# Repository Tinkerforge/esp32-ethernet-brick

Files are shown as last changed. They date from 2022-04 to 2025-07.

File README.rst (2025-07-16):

ESP32 Ethernet Brick
====================

This repository contains the firmware source code and the hardware design
files. The documentation generator configs can be found at
https://github.com/Tinkerforge/generators

Repository Overview
-------------------

.. DO NOT EDIT THIS OVERVIEW MANUALLY! CHANGE https://github.com/Tinkerforge/esp32-firmware/repo_overview.rst AND COPY THAT BLOCK INTO ALL REPOS LISTED BELOW. TODO: AUTOMATE THIS

Software
~~~~~~~~
- `esp32-firmware <https://github.com/Tinkerforge/esp32-firmware>`__  **Please report any issues concerning WARP hard- and software here!** Source code of the ESP32 firmware shared between all WARP Chargers and Energy Managers

- `tfjson <https://github.com/Tinkerforge/tfjson>`__ SAX style JSON serializer and deserializer
- `tfmodbustcp <https://github.com/Tinkerforge/tfmodbustcp>`__ Modbus TCP server and client implementation
- `tfocpp <https://github.com/Tinkerforge/tfocpp>`__ OCPP 1.6 implementation
- `tftools <https://github.com/Tinkerforge/tftools>`__ Miscellaneous tools and helpers

- `esp32-remote-access <https://github.com/Tinkerforge/esp32-remote-access>`__ Source code of the my.warp-charger.com remote access server

- `warp-charger <https://github.com/Tinkerforge/warp-charger>`__ The source code of (docs.)warp-charger.com and the printed manual, released firmwares, datasheets and documents, as well as some tools and hardware design files
- `api.warp-charger.com <https://github.com/Tinkerforge/api.warp-charger.com>`__ Serves APIs that are used by WARP Chargers to obtain relevant public information like day ahead prices
- `vislog.warp-charger.com <https://github.com/Tinkerforge/vislog.warp-charger.com>`__ Visualizes WARP Charger logs and EVSE debug protocols
- `dbus-warp-charger <https://github.com/Tinkerforge/dbus-warp-charger>`__ Integrates WARP Chargers into a Victron Energy Venus OS device (e.g. Cerbo GX)

WARP Charger Hardware
~~~~~~~~~~~~~~~~~~~~~~

- `esp32-brick <https://github.com/Tinkerforge/esp32-brick>`__ Hardware design files of the ESP32 Brick
- `evse-bricklet <https://github.com/Tinkerforge/evse-bricklet>`__  Firmware source code and hardware design files of the EVSE Bricklet
- `rs485-bricklet <https://github.com/Tinkerforge/rs485-bricklet>`__ Firmware source code and hardware design files of the RS485 Bricklet

WARP2 Charger Hardware
~~~~~~~~~~~~~~~~~~~~~~

- `esp32-ethernet-brick <https://github.com/Tinkerforge/esp32-ethernet-brick>`__ Hardware design files of the ESP32 Ethernet Brick
- `evse-v2-bricklet <https://github.com/Tinkerforge/evse-v2-bricklet>`__ Firmware source code and hardware design files of the EVSE 2.0 Bricklet
- `nfc-bricklet <https://github.com/Tinkerforge/nfc-bricklet>`__ Firmware source code and hardware design files of the NFC Bricklet

WARP3 Charger Hardware
~~~~~~~~~~~~~~~~~~~~~~

- `warp-esp32-ethernet-brick <https://github.com/Tinkerforge/warp-esp32-ethernet-brick>`__ Hardware design files of the WARP ESP32 Ethernet Brick
- `evse-v3-bricklet <https://github.com/Tinkerforge/evse-v3-bricklet>`__ Firmware source code and hardware design files of the EVSE 3.0 Bricklet
- `nfc-bricklet <https://github.com/Tinkerforge/nfc-bricklet>`__ Firmware source code and hardware design files of the NFC Bricklet

WARP Energy Manager Hardware
~~~~~~~~~~~~~~~~~~~~~~~~~~~~

- `esp32-ethernet-brick <https://github.com/Tinkerforge/esp32-ethernet-brick>`__ Hardware design files of the ESP32 Ethernet Brick
- `warp-energy-manager-bricklet <https://github.com/Tinkerforge/warp-energy-manager-bricklet>`__ Firmware source code and hardware design files of the WARP Energy Manager Bricklet

WARP Energy Manager 2.0 Hardware
~~~~~~~~~~~~~~~~~~~~~~~~~~~~~~~~

- `esp32-ethernet-brick <https://github.com/Tinkerforge/esp32-ethernet-brick>`__ Hardware design files of the ESP32 Ethernet Brick
- `warp-energy-manager-v2-bricklet <https://github.com/Tinkerforge/warp-energy-manager-v2-bricklet>`__ Firmware source code and hardware design files of the WARP Energy Manager 2.0 Bricklet
- `warp-front-panel-bricklet <https://github.com/Tinkerforge/warp-front-panel-bricklet>`__ Firmware source code and hardware design files of the WARP Front Panel Bricklet

Forked/patched projects
~~~~~~~~~~~~~~~~~~~~~~~

- `arduino-esp32 <https://github.com/Tinkerforge/arduino-esp32>`__
- `esp32-arduino-libs <https://github.com/Tinkerforge/esp32-arduino-libs>`__
- `WireGuard-ESP32-Arduino <https://github.com/Tinkerforge/WireGuard-ESP32-Arduino>`__

Repository Content
------------------

hardware/:
 * Contains KiCad project files and additionally schematics as PDF

datasheets/:
 * Contains datasheets for sensors and complex ICs that are used

Hardware
--------

The hardware is designed with the open source EDA Suite KiCad
(http://www.kicad.org). Before you are able to open the files,
you have to install the Tinkerforge kicad-libraries
(https://github.com/Tinkerforge/kicad-libraries). You can either clone
them directly in hardware/ or clone them in a separate folder and
symlink them into hardware/
(ln -s kicad_path/kicad-libraries project_path/hardware). After that you
can open the .pro file in hardware/ with KiCad and from there view and
modify the schematics and the PCB layout.

Software
--------

The software for all Bricks based on the ESP32 can be found at:
https://github.com/Tinkerforge/esp32-firmware/tree/master/software

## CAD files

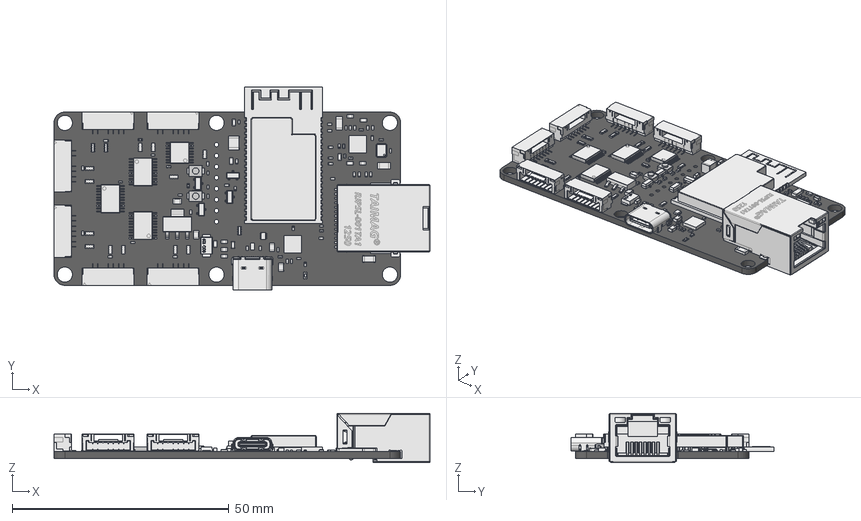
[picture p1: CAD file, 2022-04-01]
hardware/esp32-ethernet.FCStd
86.8 x 46.7 x 11.4 mm
Pcb_1a05
ESP32-WROVER-E
ESP32-WROVER-E001
ESP32-WROVER-E002
ESP32-WROVER-E003
ESP32-WROVER-E004
ESP32-WROVER-E005
ESP32-WROVER-E006
ESP32-WROVER-E007
ESP32-WROVER-E008
ESP32-WROVER-E009
ESP32-WROVER-E010
ESP32-WROVER-E011
ESP32-WROVER-E012
ESP32-WROVER-E013
ESP32-WROVER-E014
ESP32-WROVER-E015
ESP32-WROVER-E016
ESP32-WROVER-E017
ESP32-WROVER-E018
ESP32-WROVER-E019
ESP32-WROVER-E020
ESP32-WROVER-E021
ESP32-WROVER-E022
ESP32-WROVER-E023
ESP32-WROVER-E024
ESP32-WROVER-E025
ESP32-WROVER-E026
ESP32-WROVER-E027
ESP32-WROVER-E028
ESP32-WROVER-E029
ESP32-WROVER-E030
ESP32-WROVER-E031
ESP32-WROVER-E032
ESP32-WROVER-E033
ESP32-WROVER-E034
ESP32-WROVER-E035
ESP32-WROVER-E036
ESP32-WROVER-E037
ESP32-WROVER-E038
ESP32-WROVER-E039
ESP32-WROVER-E040
R107_R_0402_5E99F300 x 37
SW101_B3U_1000P[]_5F5B68B4 x 2
Q102_SOT23_5E999EC0 x 4
RP104_Cut_5E9D7D33 x 15
U203_TSSOP-20_5E99A0A3 x 3
P206_BrickletConn_7pin_5E9D989A x 6
L104_R_0603_5E999E38 x 5
USB4105
USB4106
C111_C_0805_5E999D16 x 4
U103_QFN-24_4x4mm_Pitch0.5mm_5E99F04F x 2
C107_C_0402_5E99FA0A x 19
C112_C_0603_604B6DD5 x 7
C303_C_1206_604F2960 x 3
U204_TSSOP-16_604B6FE5
C105_C_1210_604BAACF
Ethernet_Buchse
Ethernet_Buchse001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

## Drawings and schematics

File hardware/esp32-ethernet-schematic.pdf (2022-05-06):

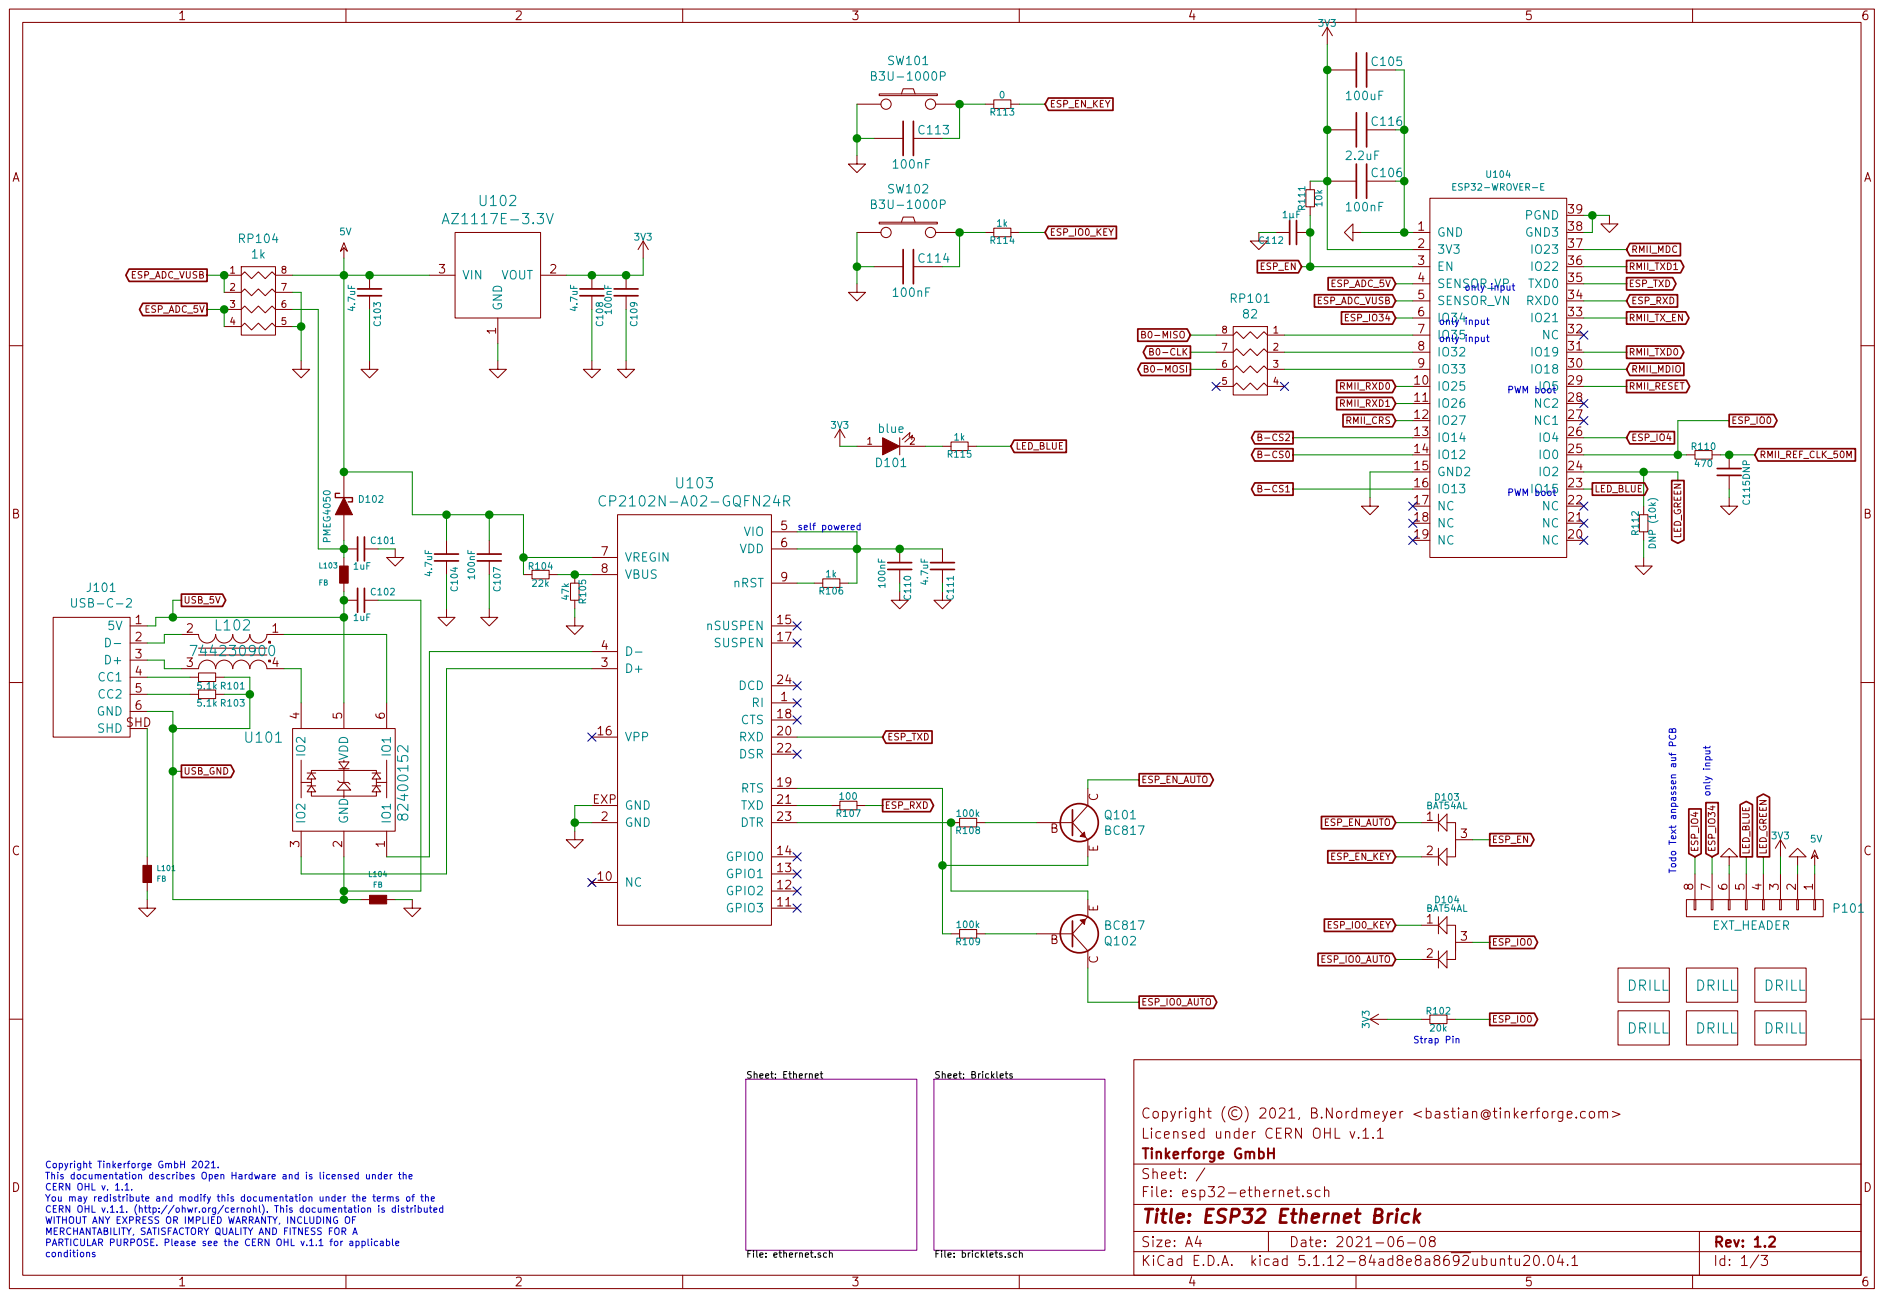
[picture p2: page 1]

Sheet: Bricklets File: bricklets.sch Sheet: Ethernet File: ethernet.sch

Licensed under CERN OHL v.1.1 Copyright (©) 2021, B.Nordmeyer <bastian@tinkerforge.com>

File: esp32-ethernet.sch Sheet: / Tinkerforge GmbH

Copyright Tinkerforge GmbH 2021. This documentation describes Open Hardware and is licensed under the CERN OHL v. 1.1. You may redistribute and modify this documentation under the terms of the CERN OHL v.1.1. (http://ohwr.org/cernohl). This documentation is distributed WITHOUT ANY EXPRESS OR IMPLIED WARRANTY, INCLUDING OF MERCHANTABILITY, SATISFACTORY QUALITY AND FITNESS FOR A

Id: 1/3 Title: ESP32 Ethernet Brick

PARTICULAR PURPOSE. Please see the CERN OHL v.1.1 for applicable

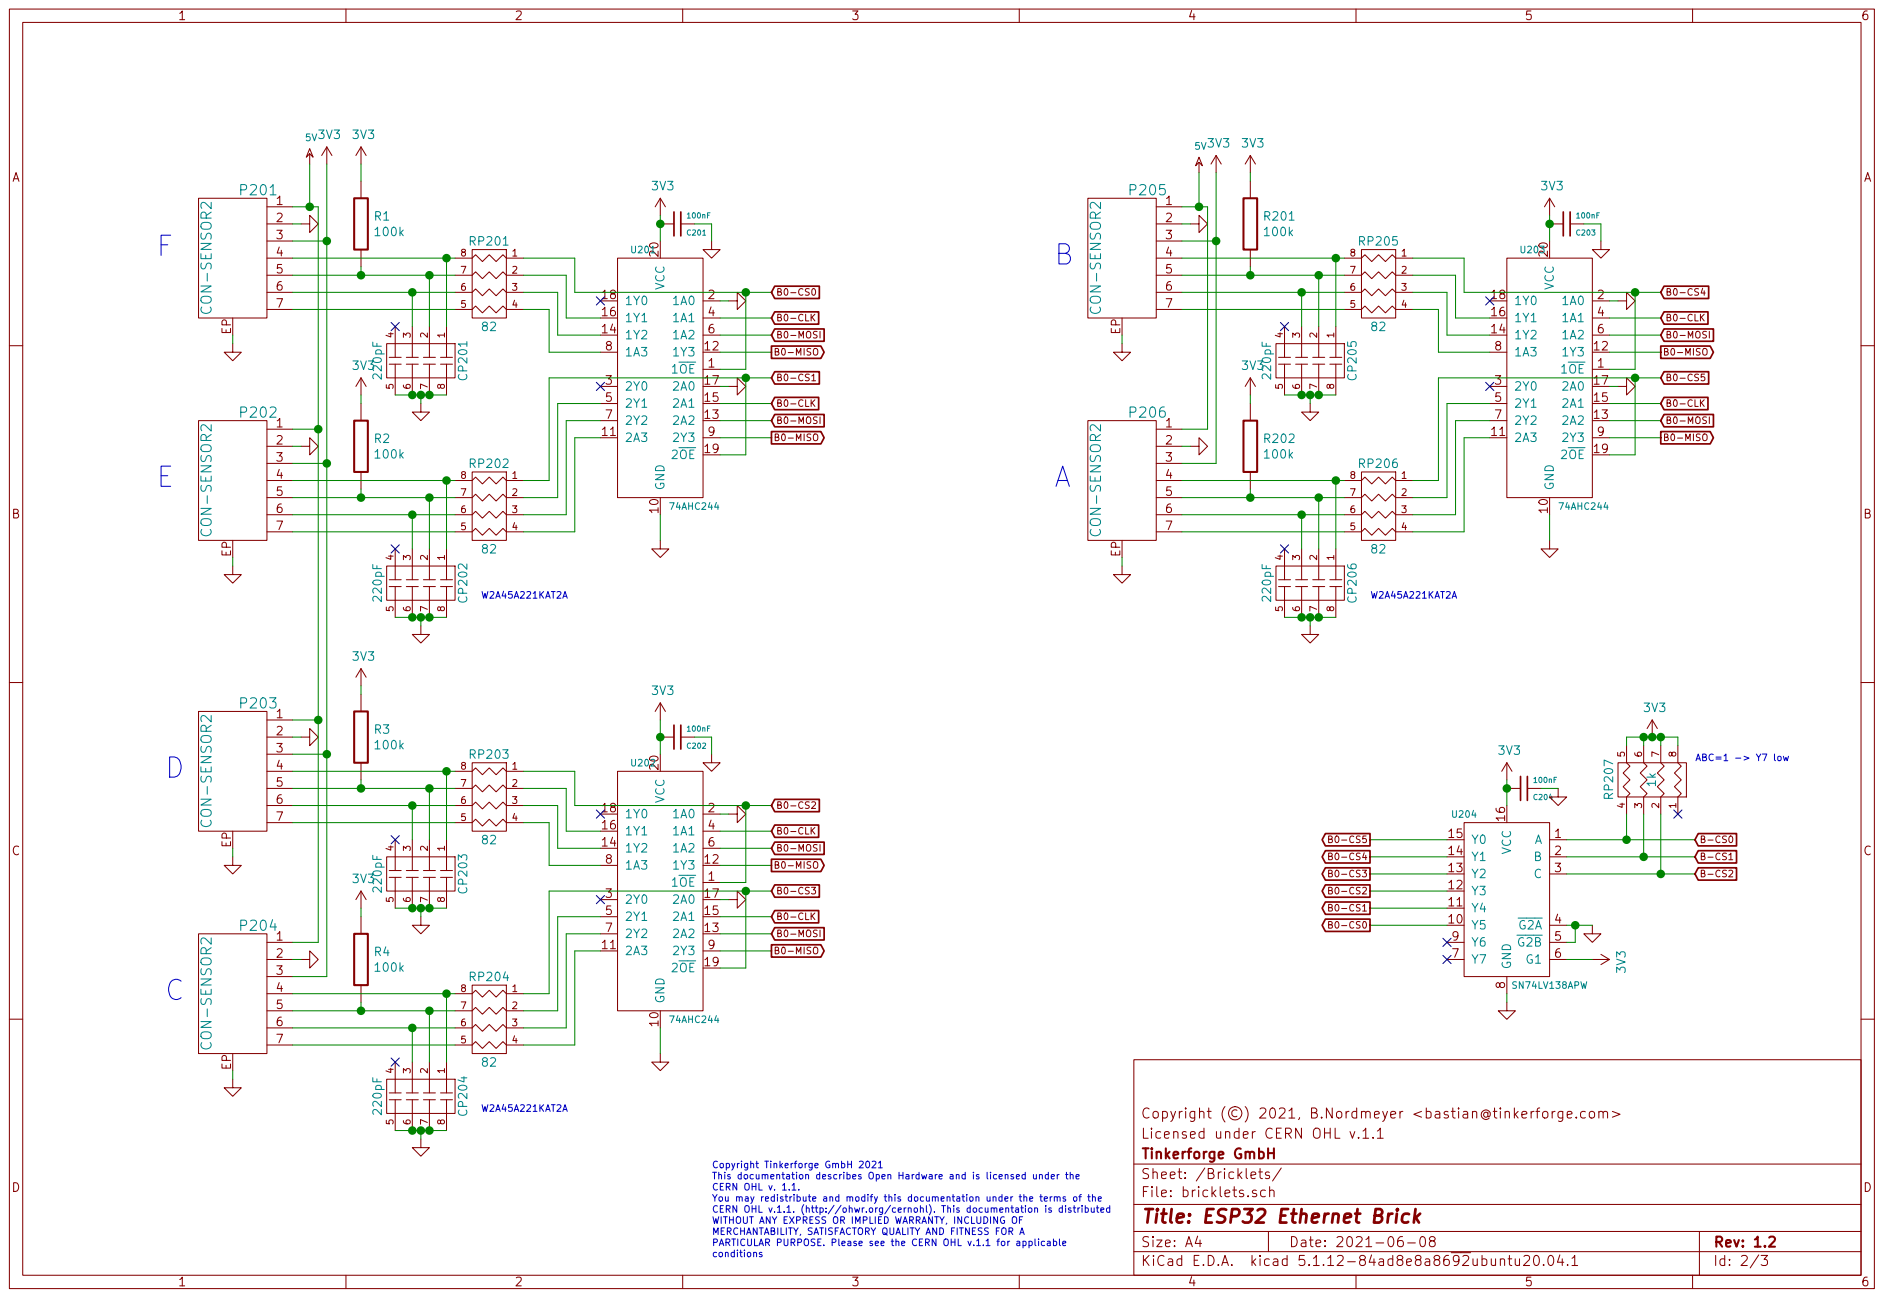
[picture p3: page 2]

Licensed under CERN OHL v.1.1 Copyright (©) 2021, B.Nordmeyer <bastian@tinkerforge.com>

File: bricklets.sch Sheet: /Bricklets/ Tinkerforge GmbH

Id: 2/3 Title: ESP32 Ethernet Brick

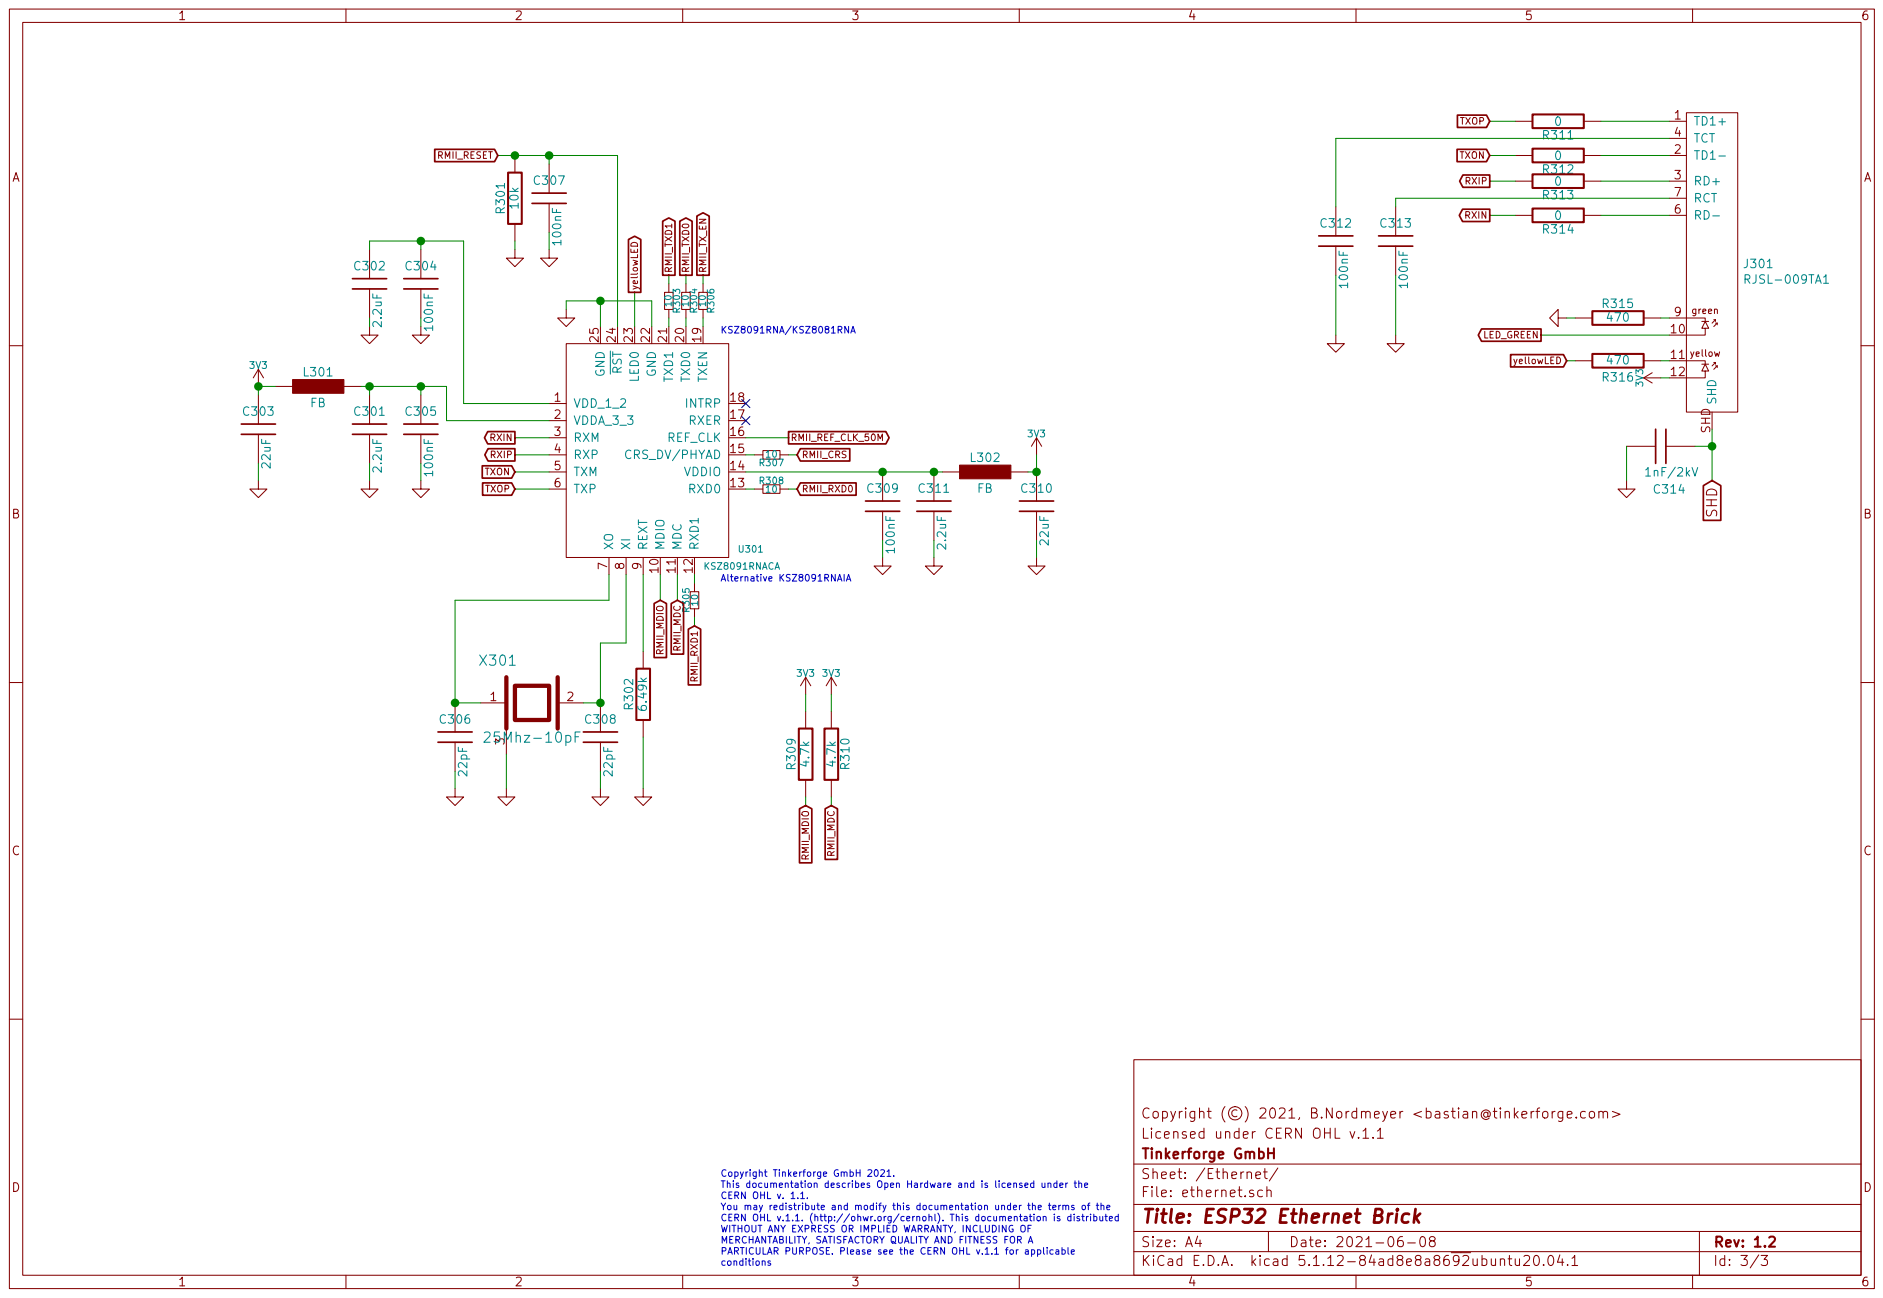
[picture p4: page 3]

Alternative KSZ8091RNAIA Copyright Tinkerforge GmbH 2021. This documentation describes Open Hardware and is licensed under the CERN OHL v. 1.1. You may redistribute and modify this documentation under the terms of the CERN OHL v.1.1. (http://ohwr.org/cernohl). This documentation is distributed WITHOUT ANY EXPRESS OR IMPLIED WARRANTY, INCLUDING OF MERCHANTABILITY, SATISFACTORY QUALITY AND FITNESS FOR A

Licensed under CERN OHL v.1.1 Copyright (©) 2021, B.Nordmeyer <bastian@tinkerforge.com>

File: ethernet.sch Sheet: /Ethernet/ Tinkerforge GmbH

Id: 3/3 Title: ESP32 Ethernet Brick

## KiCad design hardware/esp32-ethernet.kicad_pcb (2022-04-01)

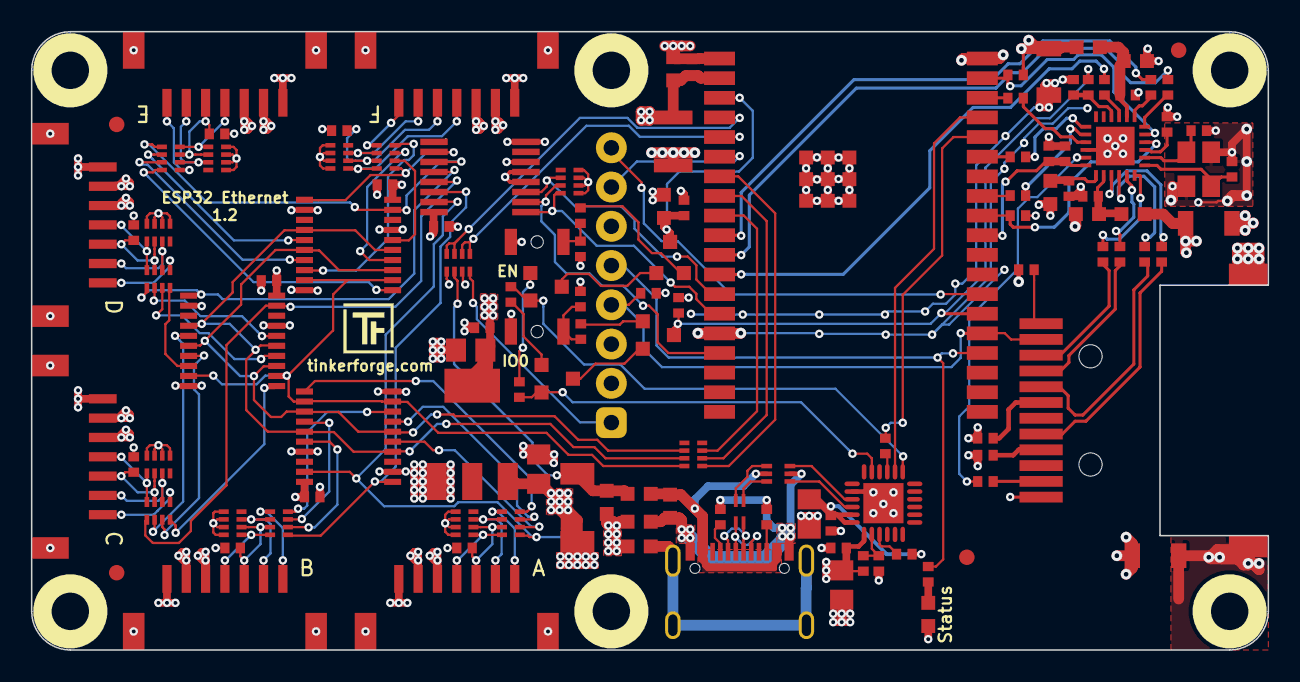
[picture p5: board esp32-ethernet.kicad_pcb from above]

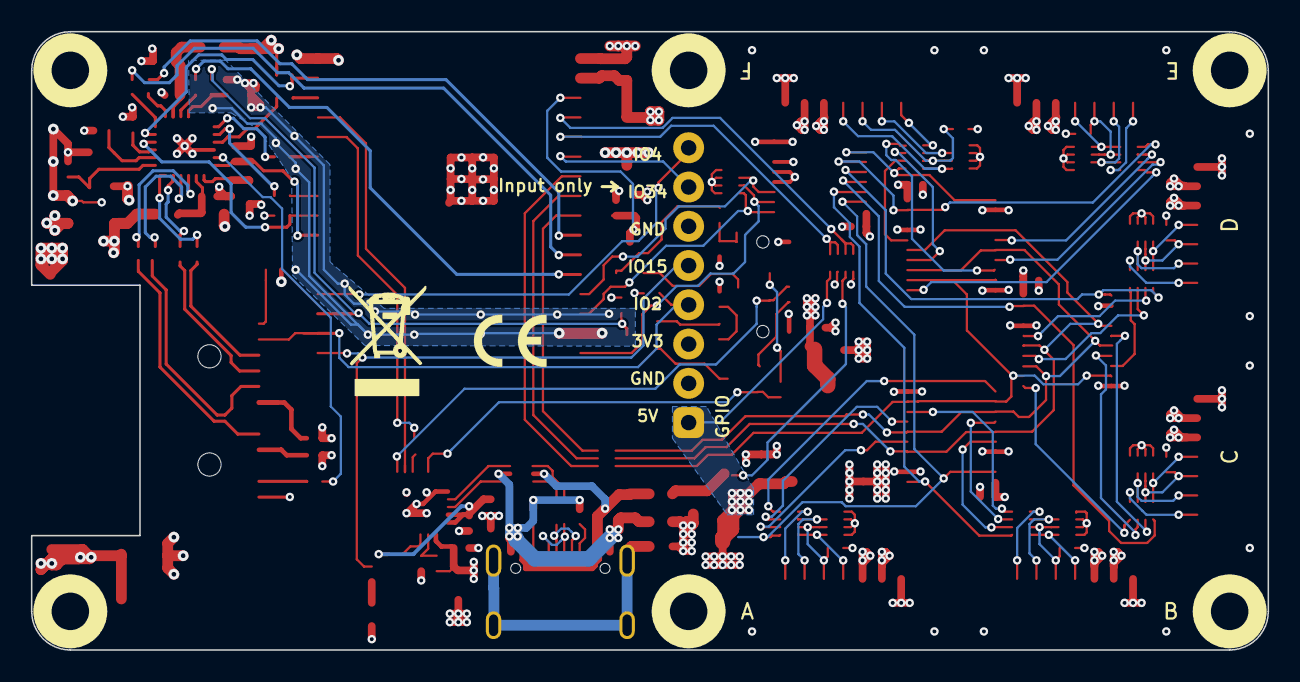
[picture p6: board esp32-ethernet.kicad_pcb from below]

Board: 4 copper layers, 80.0 x 40.0 mm, 131 parts (2 on the bottom side), 133 nets.

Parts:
C101, C102: 1uF; C0603F
C103, C104, C108, C111: 4.7uF; C0805E
C105: 100uF; C1210
C106, C107, C109, C110, C113, C114, C201, C202, C203, C204, C304, C305, C307, C309, C312, C313: 100nF; C0402F
C112: 1µF; C0603F
C115: DNP; C0402F
C116, C301, C302, C311: 2.2uF; C0603F
C303, C310: 22uF; C1206
C306, C308: 22pF; C0402F
C314: 1nF/2kV; C1206
CP201, CP202, CP203, CP204, CP205, CP206: 220pF; 4X0402
D101: blue; D0603F
D102: PMEG4050; SOD-128
D103, D104: BAT54AL; SOT23-3
F101, F102, F103, F104, F105, F106: DRILL; DRILL_NP_35
Fiducial_Mark: VAL**; Fiducial_Mark
Fiducial_Mark#2, Fiducial_Mark#3, Fiducial_Mark#4: VAL**; Fiducial_Mark
J101: USB-C-2
J301: RJSL-009TA1
L101, L103, L104, L301, L302: FB; R0603F
L102: 744230900; WE-CNSW-0603
P101: EXT_HEADER; pin_array_1x8-P2mm_D1mm
P201, P202, P203, P204, P205, P206: CON-SENSOR2
Q101, Q102: BC817; SOT23EBC
R1, R2, R3, R4, R108, R109, R201, R202: 100k; R0402F
R101, R103: 5.1k; R0402F
R102: 20k; R0402F
R104: 22k; R0402F
R105: 47k; R0402F
R106, R114, R115: 1k; R0402F
R107: 100; R0402F
R110, R315, R316: 470; R0402F
R111, R301: 10k; R0402F
R112: DNP (10k); R0402F
R113, R311, R312, R313, R314: 0; R0402F
R302: 6.49k; R0402F
R303, R304, R305, R306, R307, R308: 10; R0402F
R309, R310: 4.7k; R0402F
RP101, RP201, RP202, RP203, RP204, RP205, RP206: 82; 4X0402
RP104, RP207: 1k; 4X0402
SW101, SW102: B3U-1000P
U101: 82400152; SOT563-SPEC
U102: AZ1117E-3.3V; SOT-223
U103: CP2102N-A02-GQFN24R; QFN24-4x4mm-0.5mm
U104: ESP32-WROVER-E
U201, U202, U203: 74AHC244; TSSOP20
U204: SN74LV138APW; TSSOP16
U301: KSZ8091RNACA; QFN-24-4x4-EP
VAL: CE_5mm
VAL#2: WEEE_7mm
X301: 25Mhz-10pF; CRYSTAL_3225

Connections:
3V3: C105.2, C106.2, C108.2, C109.2, C116.2, C201.2, C202.2, C203.2, C204.2, C303.2, C310.2, D101.1, J301.12, L301.1, L302.2, P101.3, P201.3, P202.3, P203.3, P204.3, P205.3, P206.3, R1.1, R2.1, R3.1, R4.1, R102.2, R111.1, R201.1, R202.1, R309.2, R310.1, RP207.5, RP207.6, RP207.7, RP207.8, U102.2, U104.2, U201.20, U202.20, U203.20, U204.6, U204.16
5V: C103.2, C104.2, C107.2, D102.2, P101.1, P201.1, P202.1, P203.1, P204.1, P205.1, P206.1, R104.2, RP104.8, U102.3, U103.7
B0-CLK: RP101.7, U201.4, U201.15, U202.4, U202.15, U203.4, U203.15
B0-CS0: RP201.1, U201.1, U204.10
B0-CS1: RP202.1, U201.19, U204.11
B0-CS2: RP203.1, U202.1, U204.12
B0-CS3: RP204.1, U202.19, U204.13
B0-CS4: RP205.1, U203.1, U204.14
B0-CS5: RP206.1, U203.19, U204.15
B0-MISO: RP101.8, U201.9, U201.12, U202.9, U202.12, U203.9, U203.12
B0-MOSI: RP101.6, U201.6, U201.13, U202.6, U202.13, U203.6, U203.13
B-CS0: RP207.4, U104.14, U204.1
B-CS1: RP207.3, U104.16, U204.2
B-CS2: RP207.2, U104.13, U204.3
ESP_ADC_5V: RP104.3, RP104.4, U104.4
ESP_ADC_VUSB: RP104.1, RP104.2, U104.5
ESP_EN: C112.2, D103.3, R111.2, U104.3
ESP_EN_AUTO: D103.1, Q101.C
ESP_EN_KEY: D103.2, R113.2
ESP_IO0: D104.3, R102.1, R110.2, U104.25
ESP_IO0_AUTO: D104.2, Q102.C
ESP_IO0_KEY: D104.1, R114.2
ESP_IO4: P101.8, U104.26
ESP_IO34: P101.7, U104.6
ESP_RXD: R107.2, U104.34
ESP_TXD: U103.20, U104.35
GND: C101.1, C103.1, C104.1, C105.1, C106.1, C107.1, C108.1, C109.1, C110.1, C111.1, C112.1, C113.2, C114.2, C115.2, C116.1, C201.1, C202.1, C203.1, C204.1, C301.1, C302.1, C303.1, C304.1, C305.1, C306.1, C307.1, C308.1, C309.1, C310.1, C311.1, C312.1, C313.1, C314.2, CP201.5, CP201.6, CP201.7, CP201.8, CP202.5, CP202.6, CP202.7, CP202.8, CP203.5, CP203.6, CP203.7, CP203.8, CP204.5, CP204.6, CP204.7, CP204.8, CP205.5, CP205.6, CP205.7, CP205.8, CP206.5, CP206.6, CP206.7, CP206.8, L101.1, L104.2, P101.2, P101.6, P201.2, P201.EP, P202.2, P202.EP, P203.2, P203.EP, P204.2, P204.EP, P205.2, P205.EP, P206.2, P206.EP, R105.1, R112.2, R301.1, R302.1, R315.1, RP104.5, RP104.7, SW101.1, SW102.1, U102.1, U103.2, U103.EXP, U104.1, U104.15, U104.38, U104.39, U201.2, U201.10, U201.17, U202.2, U202.10, U202.17, U203.2, U203.10, U203.17, U204.4, U204.5, U204.8, U301.22, U301.25, X301.3
LED_BLUE: P101.5, R115.2, U104.23
LED_GREEN: J301.10, P101.4, R112.1, U104.24
unnamed: C101.2, D102.1, L103.2, RP104.6
unnamed: C110.2, C111.2, R106.2, U103.5, U103.6
unnamed: C113.1, R113.1, SW101.2
unnamed: C114.1, R114.1, SW102.2
unnamed: C301.2, C305.2, L301.2, U301.2
unnamed: C302.2, C304.2, U301.1
unnamed: C306.2, U301.7, X301.1
unnamed: C308.2, U301.8, X301.2
unnamed: C309.2, C311.2, L302.1, U301.14
unnamed: C312.2, J301.4
unnamed: C313.2, J301.7
unnamed: CP201.1, P201.4, RP201.8
unnamed: CP201.2, P201.5, R1.2, RP201.7
unnamed: CP201.3, P201.6, RP201.6
unnamed: CP202.1, P202.4, RP202.8
unnamed: CP202.2, P202.5, R2.2, RP202.7
unnamed: CP202.3, P202.6, RP202.6
unnamed: CP203.1, P203.4, RP203.8
unnamed: CP203.2, P203.5, R3.2, RP203.7
unnamed: CP203.3, P203.6, RP203.6
unnamed: CP204.1, P204.4, RP204.8
unnamed: CP204.2, P204.5, R4.2, RP204.7
unnamed: CP204.3, P204.6, RP204.6
unnamed: CP205.1, P205.4, RP205.8
unnamed: CP205.2, P205.5, R201.2, RP205.7
unnamed: CP205.3, P205.6, RP205.6
unnamed: CP206.1, P206.4, RP206.8
unnamed: CP206.2, P206.5, R202.2, RP206.7
unnamed: CP206.3, P206.6, RP206.6
unnamed: D101.2, R115.1
unnamed: J101.2, L102.2
unnamed: J101.3, L102.3
unnamed: J101.4, R101.2
unnamed: J101.5, R103.2
unnamed: J101.SHD, L101.2
unnamed: J301.1, R311.1
unnamed: J301.2, R312.1
unnamed: J301.3, R313.1
unnamed: J301.6, R314.1
unnamed: J301.9, R315.2
unnamed: J301.11, R316.2
unnamed: L102.1, U101.6
unnamed: L102.4, U101.4
unnamed: P201.7, RP201.5
unnamed: P202.7, RP202.5
unnamed: P203.7, RP203.5
unnamed: P204.7, RP204.5
unnamed: P205.7, RP205.5
unnamed: P206.7, RP206.5
unnamed: Q101.B, R108.2
unnamed: Q101.E, R109.1, U103.19
unnamed: Q102.B, R109.2
unnamed: Q102.E, R108.1, U103.23
unnamed: R104.1, R105.2, U103.8
unnamed: R106.1, U103.9
unnamed: R107.1, U103.21
unnamed: R302.2, U301.9
unnamed: R303.1, U301.21
unnamed: R304.1, U301.20
unnamed: R305.1, U301.12
unnamed: R306.1, U301.19
unnamed: R307.1, U301.15
unnamed: R308.2, U301.13
unnamed: RP101.1, U104.7
unnamed: RP101.2, U104.8
unnamed: RP101.3, U104.9
unnamed: RP201.2, U201.16
unnamed: RP201.3, U201.14
unnamed: RP201.4, U201.8
unnamed: RP202.2, U201.5
unnamed: RP202.3, U201.7
unnamed: RP202.4, U201.11
unnamed: RP203.2, U202.16
unnamed: RP203.3, U202.14
unnamed: RP203.4, U202.8
unnamed: RP204.2, U202.5
unnamed: RP204.3, U202.7
unnamed: RP204.4, U202.11
unnamed: RP205.2, U203.16
unnamed: RP205.3, U203.14
unnamed: RP205.4, U203.8
unnamed: RP206.2, U203.5
unnamed: RP206.3, U203.7
unnamed: RP206.4, U203.11
unnamed: U101.1, U103.4
unnamed: U101.3, U103.3
RMII_CRS: R307.2, U104.12
RMII_MDC: R310.2, U104.37, U301.11
RMII_MDIO: R309.1, U104.30, U301.10
RMII_REF_CLK_50M: C115.1, R110.1, U301.16
RMII_RESET: C307.2, R301.2, U104.29, U301.24
RMII_RXD0: R308.1, U104.10
RMII_RXD1: R305.2, U104.11
RMII_TXD0: R304.2, U104.31
RMII_TXD1: R303.2, U104.36
RMII_TX_EN: R306.2, U104.33
RXIN: R314.2, U301.3
RXIP: R313.2, U301.4
SHD: C314.1, J301.SHD
TXON: R312.2, U301.5
TXOP: R311.2, U301.6
USB_5V: C102.2, J101.1, L103.1, U101.5
USB_GND: C102.1, J101.6, L104.1, R101.1, R103.1, U101.2
yellowLED: R316.1, U301.23

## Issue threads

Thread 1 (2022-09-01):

The cache file is missing and project can

greenscreenflicker, 2022-09-01:

greenscreenflicker, 2022-09-01:
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

greenscreenflicker, 2022-09-01:
@batti

normaldotcom, 2025-01-01:
Wanted to second this--could you please upload the cache file? Thanks!

borg42, 2025-01-01:
I don't think the cache file needs to be commited. If i klick "Load Without Cache File" it all opens fine for me. Did you add the kicad-libraries: https://github.com/Tinkerforge/kicad-libraries/ ?

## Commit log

2021-03-12 add hardware files, routing not finised
    [bricklets.sch, esp32-ethernet.kicad_pcb, esp32-ethernet.sch]
2021-03-12 add missing file
    [ethernet.sch]
2021-03-12 moure routing
    [bricklets.sch, esp32-ethernet.kicad_pcb, esp32-ethernet.sch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]
2021-03-12 more routing
    [esp32-ethernet.kicad_pcb]
2021-03-15 routing finished
    [esp32-ethernet.kicad_pcb, ethernet.sch]
2021-03-15 improve layer design
    [esp32-ethernet.kicad_pcb, esp32-ethernet.sch, ethernet.sch]
2021-03-15 version 1.0
    [bricklets.sch, esp32-ethernet.kicad_pcb]
2021-03-24 move signal direction
    [esp32-ethernet.sch]
2021-04-16 fix port description
    [bricklets.sch, esp32-ethernet.kicad_pcb]
2021-04-20 version 1.1
    * change SPI pins
    * change GPIO header pinout
    * add Silkscreen
    [esp32-ethernet.kicad_pcb, esp32-ethernet.sch, ethernet.sch]
2021-04-20 specify ethernet ic
    [esp32-ethernet.kicad_pcb, ethernet.sch]
2021-04-20 ordered prototype
    [esp32-ethernet.kicad_pcb]
2021-05-06 version 1.2
    change poe header to standard
    change Ethernet mounting vias position
    change 1uF capacitors to 0603
    [esp32-ethernet.kicad_pcb, esp32-ethernet.sch, ethernet.sch]
2021-05-12 bugfix: add missing 20k GPIO0 strapping resistor
    [esp32-ethernet.kicad_pcb, esp32-ethernet.sch]
2021-06-08 version 1.2 - change ethernet jack
    [bricklets.sch, esp32-ethernet.kicad_pcb, esp32-ethernet.sch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]
2021-06-11 fix push button footprint type
    [esp32-ethernet.kicad_pcb]
2021-06-25 fix esp32 3d model
    [esp32-ethernet.kicad_pcb]
2021-07-19 change crystal
    [esp32-ethernet.kicad_pcb, ethernet.sch]
2021-08-25 fix wrover footprint gnd pads
    [esp32-ethernet.kicad_pcb]
2021-08-25 fix ground pad layout
    [esp32-ethernet.kicad_pcb]
2021-09-15 added esp32 ethernet PSU
    [esp32-ethernet-PSU.kicad_pcb, esp32-ethernet-PSU.sch]
2021-09-21 add new pcb data with fixed u104 ground
2021-10-07 added universal esp32 psu
    [esp32-PSU.kicad_pcb, esp32-PSU.sch]
2021-10-08 universal PSU: changed silkscreen
    [esp32-PSU.kicad_pcb]
2021-10-25 Update KiCad link
    https://www.kicad.org/blog/2021/10/Avoid-links-to-former-kicad-domain/
2021-10-25 fix eth jack <-> pcb outline distance
    [esp32-ethernet.kicad_pcb]
2021-11-02 increase rj45 cutout, change drill diameters
    [esp32-ethernet.kicad_pcb, esp32-ethernet.sch]
2022-01-31 add schematic
2022-03-14 add 3d file
    [esp32-PSU.step]
2022-04-01 add 3d model for esp32 wrover e
    [esp32-ethernet.kicad_pcb]
2022-04-01 add 3d files
    [esp32-ethernet.FCStd]
2022-04-01 cleanup, power supply got its own repository
    [esp32-PSU.kicad_pcb, esp32-PSU.sch, esp32-PSU.step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]
2022-05-06 fix symbols
    [esp32-ethernet.sch]
2023-12-27 rename and add version 1.2
    [bricklets.sch, esp32-ethernet-warp.kicad_pcb, esp32-ethernet-warp.kicad_sch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]
2023-12-27 version 1.3 finished
    [esp32-ethernet-warp.kicad_pcb, esp32-ethernet-warp.kicad_sch]
2024-01-12 fix ethernet bug
    [esp32-ethernet-warp.kicad_pcb]
2024-01-12 Revert "fix ethernet bug"
    This reverts commit b0ba0365b1ecd3ee5b273f32dcba04a8b2befd97.
    [esp32-ethernet-warp.kicad_pcb]
2024-01-12 Revert "add missing file"
    This reverts commit 4856a2bd49fd03c8105c91ae49436aba15090b3a.
    [ethernet.kicad_sch]
2024-01-12 Revert "add missing file"
    This reverts commit f7ae1956097a5ea4dbced1515f2674d53ed18ee5.
    [bricklets.kicad_sch]
2024-01-12 Revert "version 1.3 finished"
    This reverts commit c7f26ed94f03ba8104635e5142b3afb52f15755f.
    [esp32-ethernet-warp.kicad_pcb, esp32-ethernet-warp.kicad_sch]
2024-01-12 Revert "rename and add version 1.2"
    This reverts commit b7bde1c38ce2ff4bc806fd67a05c147ad89dd0a9.
    [bricklets.sch, esp32-ethernet-warp.kicad_pcb, esp32-ethernet-warp.kicad_sch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]
2024-01-12 Add hint that software can be found in esp32-firmware git
